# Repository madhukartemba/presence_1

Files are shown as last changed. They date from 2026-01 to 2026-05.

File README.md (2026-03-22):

# Presence 1

Presence 1 is a mmWave radar–based presence sensor featuring an ambient light sensor, NeoPixel RGB LED, and capacitive touch switch.  
It is designed for seamless integration with Home Assistant.

Build commands:
Python version 3.12
Esphome version 2026.1.2
Example: esphome -s device_id 3 run prd/presence_1_basic/presence_1_basic.yaml

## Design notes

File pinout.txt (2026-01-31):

| Device | Signal | GPIO |
| --- | --- | --- |
| LD2420 | TX → ESP | GPIO5 |
| LD2420 | RX ← ESP | GPIO4 |
| LD2420 | D-OUT | GPIO7 |
| VEML7700 | SDA | GPIO8 |
| VEML7700 | SCL | GPIO9 |
| Push Button | Input | GPIO3 |
| Neopixel | Data | GPIO6 |
| Buzzer | PWM | GPIO21 |

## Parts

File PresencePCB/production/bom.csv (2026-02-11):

Designator | Footprint | Quantity | Value | LCSC Part #
D1, D2, D3, D4, D5 | LED_WS2812B-2020_PLCC4_2.0x2.0mm | 5 | WS2812B-2020
ESP32C3 | MODULE_ESP32-C3_SUPERMINI_TH | 1 | ESP32-C3_SUPERMINI_TH
LD2420 | LD2420_Module | 1 | LD2420_Module
R_OUT1 | 0805 | 1 | 0R
TP223B1 | TP223B_Module | 1 | TP223B
VEML7700 | VEML7700_Module | 1 | VEML7700

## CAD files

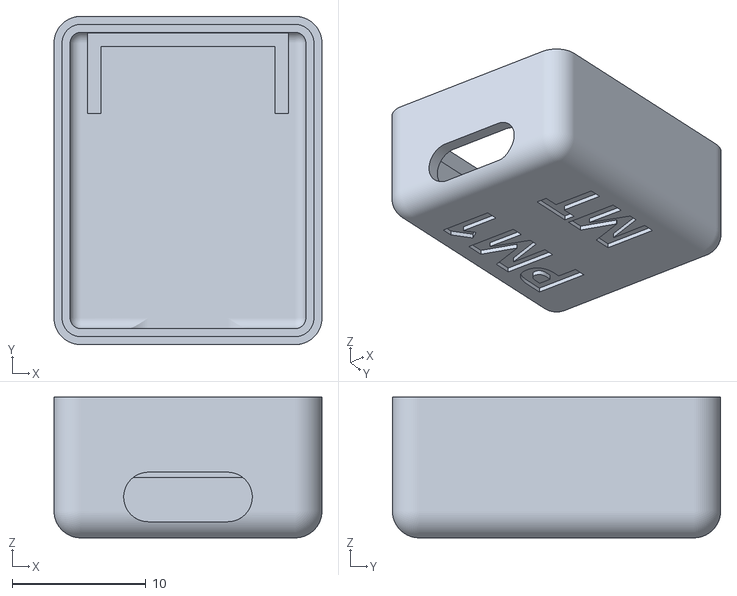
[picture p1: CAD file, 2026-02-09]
3D_print/BLE_Radar/BLE_Bottom.stl
20.0 x 24.5 x 10.5

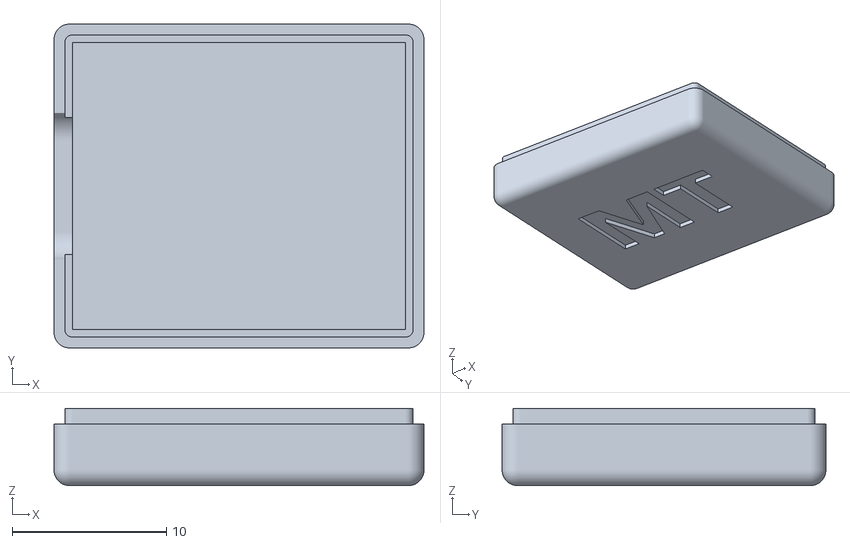
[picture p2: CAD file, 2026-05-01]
3D_print/ESP_Click_Receiver/Base.stl
24.0 x 21.0 x 5.00

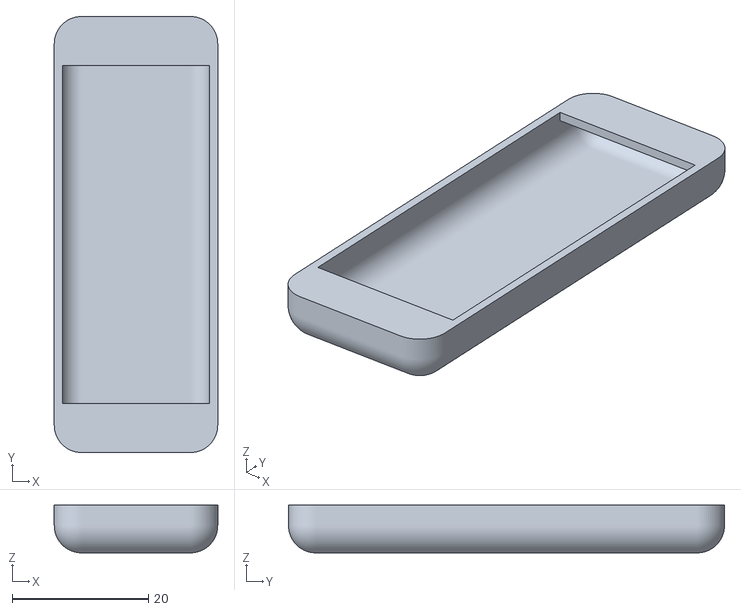
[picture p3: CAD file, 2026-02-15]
3D_print/Presence1Final/SwitchCover.stl
24.0 x 64.0 x 7.00

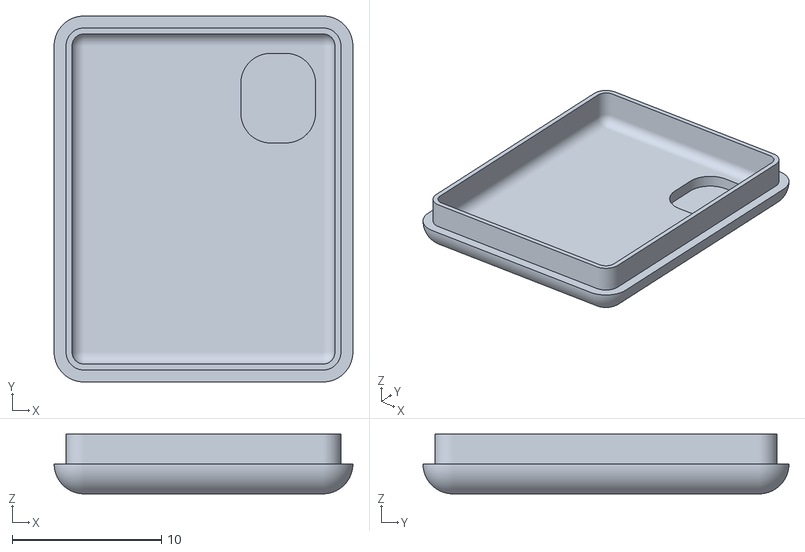
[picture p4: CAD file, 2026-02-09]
3D_print/BLE_Radar/BLE_Top.stl
20.0 x 24.5 x 4.00

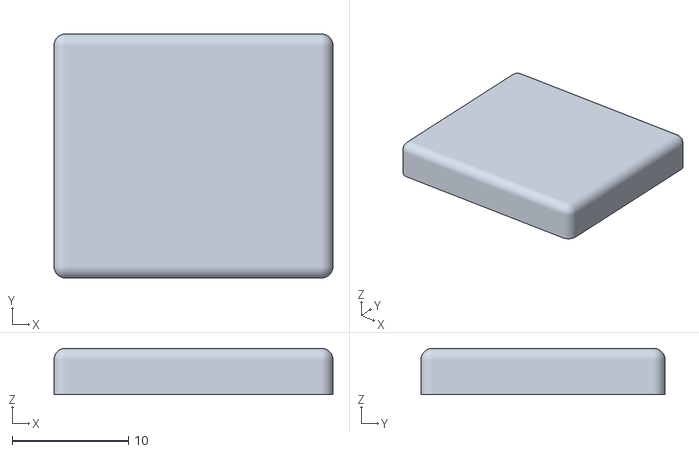
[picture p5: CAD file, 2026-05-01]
3D_print/ESP_Click_Receiver/Top.stl
24.0 x 21.0 x 4.00

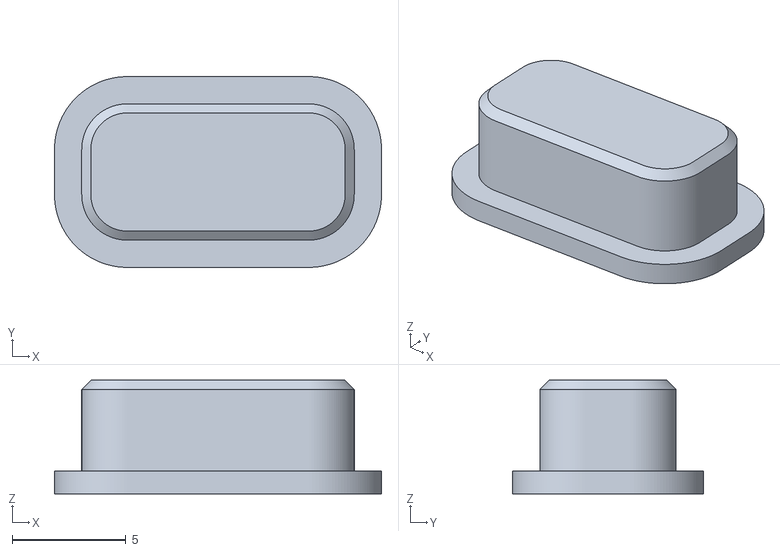
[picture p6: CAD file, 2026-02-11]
3D_print/Presence1Final/Button.stl
14.4 x 8.40 x 5.00

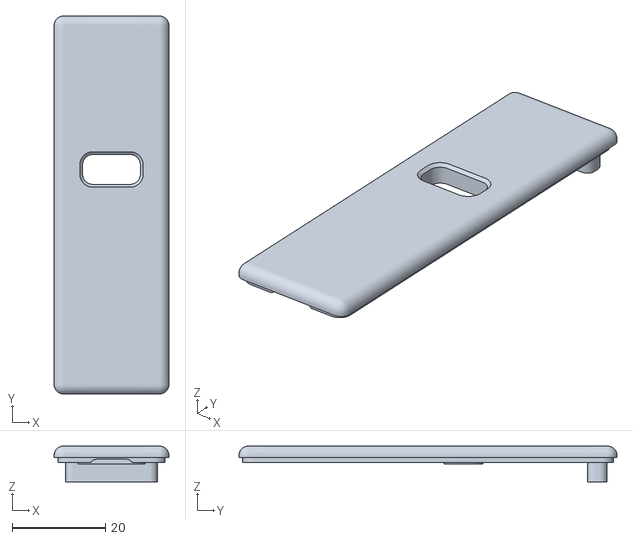
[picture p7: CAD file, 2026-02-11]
3D_print/Presence1Final/Top.stl
24.6 x 81.2 x 7.70

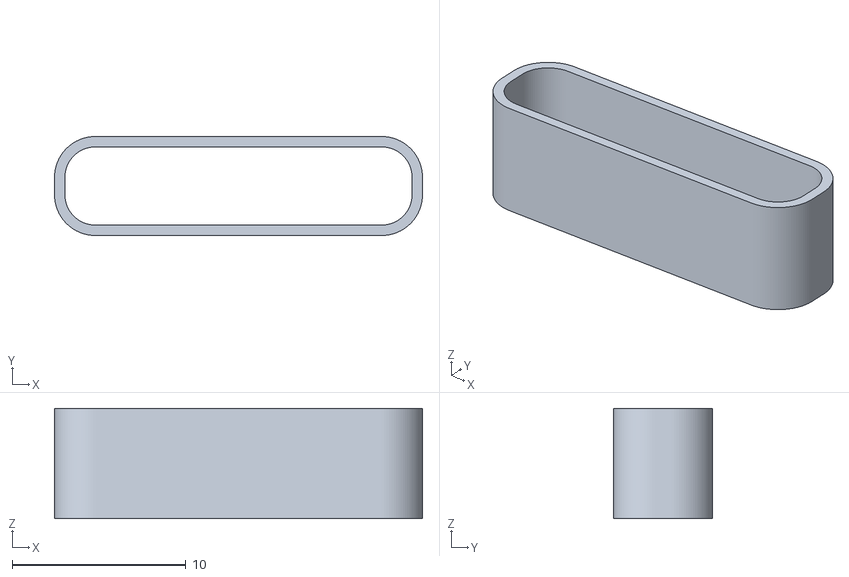
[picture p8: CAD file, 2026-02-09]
3D_print/Presence1Final/NeoCover.stl
21.2 x 5.70 x 6.35

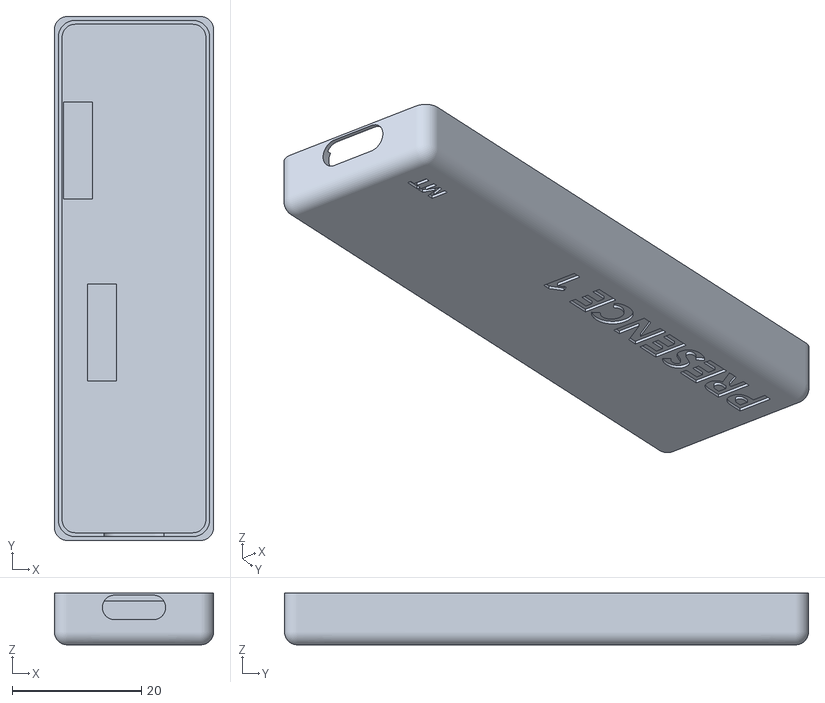
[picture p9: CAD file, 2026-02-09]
3D_print/Presence1Final/Bottom.stl
24.6 x 81.2 x 8.00

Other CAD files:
3D_print/Presence1Final/Presence 1.f3d

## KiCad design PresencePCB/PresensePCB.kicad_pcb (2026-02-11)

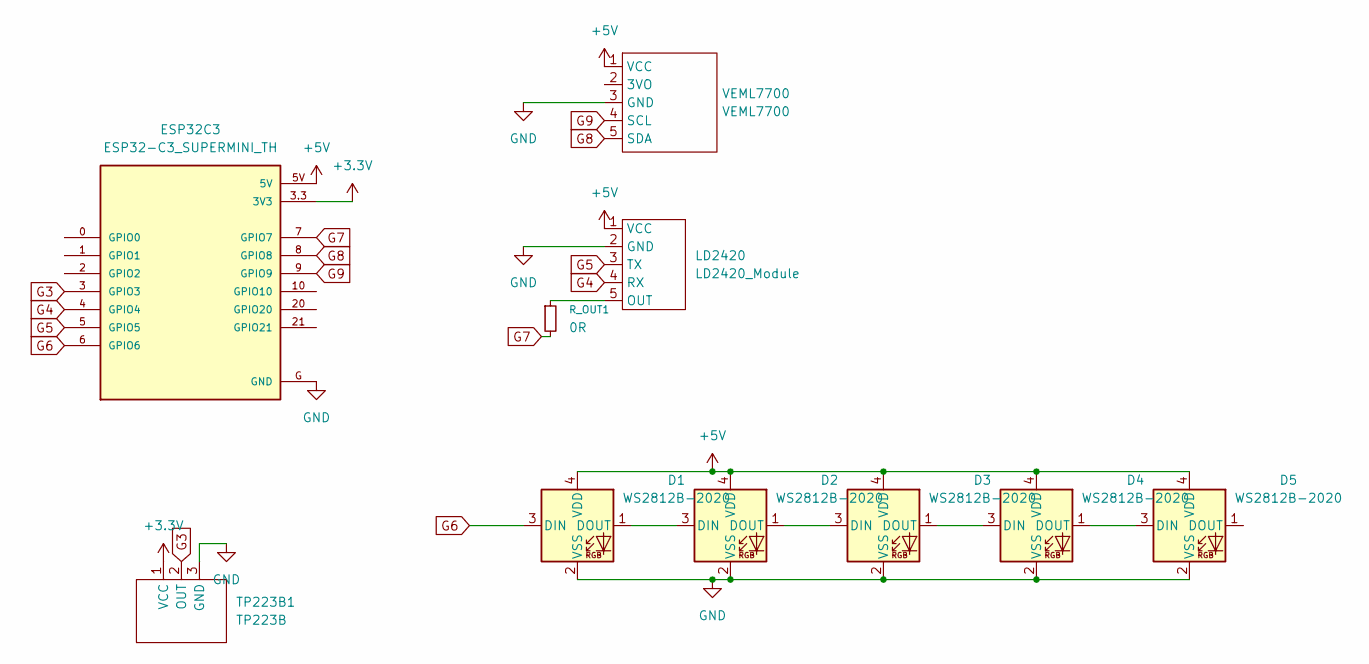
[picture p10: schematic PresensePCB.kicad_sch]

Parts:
D1, D2, D3, D4, D5: WS2812B-2020; LED_WS2812B-2020_PLCC4_2.0x2.0mm
ESP32C3: ESP32-C3_SUPERMINI_TH; MODULE_ESP32-C3_SUPERMINI_TH
LD2420: LD2420_Module
R_OUT1: 0R; R_0805_2012Metric_Pad1.20x1.40mm_HandSolder
TP223B1: TP223B; TP223B_Module
VEML7700: VEML7700; VEML7700_Module

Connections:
+3.3V: ESP32C3.3.3 (3V3), TP223B1.1 (VCC)
+5V: D1.4 (VDD), D2.4 (VDD), D3.4 (VDD), D4.4 (VDD), D5.4 (VDD), ESP32C3.5V, LD2420.1 (VCC), VEML7700.1 (VCC)
G3: ESP32C3.3 (GPIO3), TP223B1.2 (OUT)
G4: ESP32C3.4 (GPIO4), LD2420.4 (RX)
G5: ESP32C3.5 (GPIO5), LD2420.3 (TX)
G6: D1.3 (DIN), ESP32C3.6 (GPIO6)
G7: ESP32C3.7 (GPIO7), R_OUT1.2
G8: ESP32C3.8 (GPIO8), VEML7700.5 (SDA)
G9: ESP32C3.9 (GPIO9), VEML7700.4 (SCL)
GND: D1.2 (VSS), D2.2 (VSS), D3.2 (VSS), D4.2 (VSS), D5.2 (VSS), ESP32C3.G (GND), LD2420.2 (GND), TP223B1.3 (GND), VEML7700.3 (GND)
unnamed: D1.1 (DOUT), D2.3 (DIN)
unnamed: D2.1 (DOUT), D3.3 (DIN)
unnamed: D3.1 (DOUT), D4.3 (DIN)
unnamed: D4.1 (DOUT), D5.3 (DIN)
unnamed: LD2420.5 (OUT), R_OUT1.1

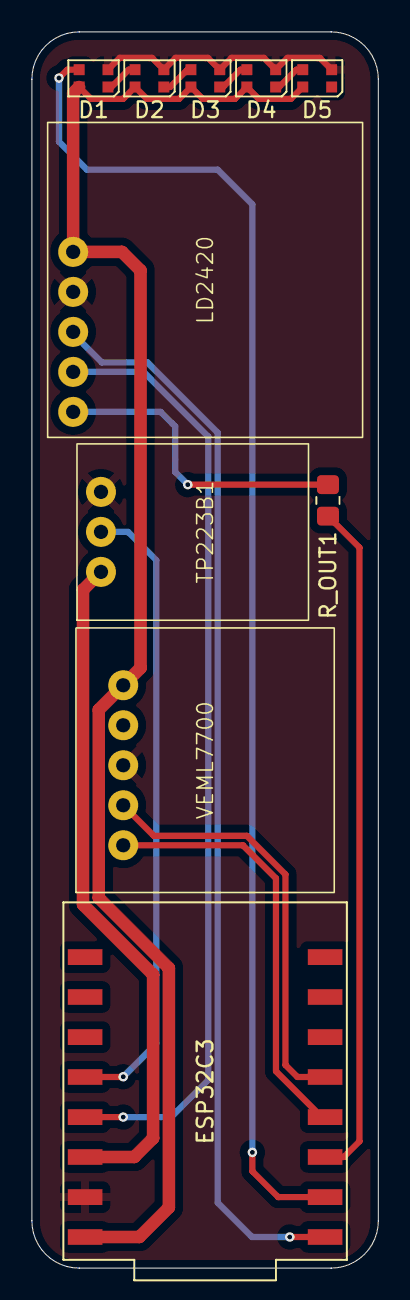
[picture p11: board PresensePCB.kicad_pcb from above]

Board: 2 copper layers, 22.0 x 78.5 mm, 10 parts (0 on the bottom side), 15 nets.

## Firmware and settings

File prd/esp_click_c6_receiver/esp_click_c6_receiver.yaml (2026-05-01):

# Minimal ESP32-C6 bridge using modular `EspClickBridge` (no LED strip).
# Copy this folder beside `esp_click_bridge/` as in this repo, or adjust `includes` paths.
substitutions:
  device_id: 0

esphome:
  name: esp-click-c6-receiver-${device_id}
  friendly_name: ESP Click C6 Receiver ${device_id}
  includes:
    - ../esp_click_bridge/esp_click_bridge.h
    - esp_now_connector.h
  platformio_options:
    lib_deps:
      - bblanchon/ArduinoJson@6.21.3
  on_boot:
    - priority: 600
      then:
        - script.execute: play_boot

esp32:
  board: esp32-c6-devkitc-1
  variant: esp32c6
  framework:
    type: esp-idf
    sdkconfig_options:
      # Work around ESP-IDF mbedTLS GCM alt-linking mismatch on C6 builds.
      # Using software AES restores standard mbedtls_gcm_* symbols.
      CONFIG_MBEDTLS_HARDWARE_AES: "n"

logger:
  level: DEBUG

api:

ota:
  - platform: esphome

wifi:
  ssid: !secret wifi_ssid
  password: !secret wifi_password
  power_save_mode: none
  on_connect:
    then:
      - script.stop: play_wifi_connecting
      - script.execute: play_wifi_connected
  on_disconnect:
    then:
      - script.execute: play_wifi_connecting

mqtt:
  broker: homeassistant.local
  username: !secret mqtt_username
  password: !secret mqtt_password
  discovery: false
  on_connect:
    - lambda: |-
        mqtt_ensure_device_sync_subscription();

espnow:
  auto_add_peer: true
  on_broadcast:
    then:
      - lambda: |-
          handle_espnow_packet(info.src_addr, data, size);
  on_receive:
    then:
      - lambda: |-
          handle_espnow_packet(info.src_addr, data, size);

# ====================
# STATUS LED (single WS2812 NeoPixel on GPIO18) — internal-only
# ====================
light:
  - platform: esp32_rmt_led_strip
    name: "Status LED"
    id: status_led
    pin: GPIO18
    num_leds: 1
    rgb_order: GRB
    chipset: WS2812
    internal: true
    default_transition_length: 0s
    # Linear gamma to avoid quantization stutter at the tail of fade-outs:
    # with gamma 2.8, ~30% of the brightness slider maps to physical 0 or 1
    # on an 8-bit WS2812, which makes the LED dwell at "1/255" before snapping
    # off. Linear keeps the steps even.
    gamma_correct: 1.0
    restore_mode: ALWAYS_OFF
    effects:
      # Slow breathing reused for pairing mode (magenta) and wifi-connecting (blue).
      # Color is captured on effect start; this effect drives brightness only.
      # Brightness range: (max_slider * 0.20) → max_slider, smoothstepped over a
      # 3 s period. Built-in `pulse` effect doesn't accept a dynamic max, so we
      # roll our own lambda effect that reads the user's max-brightness slider.
      - lambda:
          name: "Status Pulse"
          update_interval: 30ms
          lambda: |-
            static uint32_t cycle_start_ms = 0;
            if (initial_run) {
              cycle_start_ms = millis();
            }
            const uint32_t period_ms = 3000;
            const float t = (float)((millis() - cycle_start_ms) % period_ms) /
                            (float)period_ms;
            const float w = (t < 0.5f) ? (t * 2.0f) : (2.0f * (1.0f - t));
            const float s = w * w * (3.0f - 2.0f * w);
            const float max_b = id(led_max_brightness_pct).state / 100.0f;
            const float min_b = 0.20f * max_b;
            const float br = min_b + (max_b - min_b) * s;
            auto call = id(status_led).turn_on();
            call.set_transition_length(0);
            call.set_brightness(br);
            call.set_publish(false);
            call.set_save(false);
            call.perform();

interval:
  - interval: 50ms
    then:
      # Auto-close pairing mode once a device finishes pairing.
      - if:
          condition:
            lambda: return g_request_close_pairing_mode && pairing_mode_active;
          then:
            - lambda: |-
                g_request_close_pairing_mode = false;
            - switch.turn_off: pairing_mode_switch
      # Dispatch LED feedback requests latched from the EspClickBridge callback
      # (e.g. green on successful pairing, red on unpair, white/yellow/blue on
      # remote button press). See esp_now_connector.h.
      - if:
          condition:
            lambda: 'return esp_click_led_request().pending;'
          then:
            - lambda: 'esp_click_led_request().pending = false;'
            - script.execute:
                id: flash_color
                r: !lambda 'return esp_click_led_request().r / 255.0f;'
                g: !lambda 'return esp_click_led_request().g / 255.0f;'
                b: !lambda 'return esp_click_led_request().b / 255.0f;'
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

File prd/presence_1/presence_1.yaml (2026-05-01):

esphome:
  name: presence_node_${device_id}
  friendly_name: PresenceNode_${device_id}
  includes:
    - ../esp_click_bridge/esp_click_bridge.h
    - espnow_handler.h
    - led_engine.h
  platformio_options:
    lib_deps:
      - Xylopyrographer/LiteLED@3.0.1
      - bblanchon/ArduinoJson@6.21.3 # Required to parse the MAC array
  on_boot:
    - priority: 550
      then:
        - lambda: |-
            led_set_bright_lux_threshold(id(led_bright_lux_max));
    - priority: 600
      then:
        - globals.set: { id: motion_enabled, value: 'true' }
        - lambda: |-
            led_init();
            led_play_boot();

esp32:
  board: esp32-c3-devkitm-1
  framework:
    type: arduino

logger:
  baud_rate: 115200

api:

ota:
  - platform: esphome

wifi:
  ssid: !secret wifi_ssid
  password: !secret wifi_password
  power_save_mode: none
  ap:
    ssid: "PresenceNode_${device_id}_Setup"
    password: ""

captive_portal:


mqtt:
  broker: homeassistant.local
  username: !secret mqtt_username
  password: !secret mqtt_password
  discovery: false # Disable HA discovery
  # Device list: esp_click/device/<mac> handled in espnow_handler.h (needs topic + payload).
  on_connect:
    - mqtt.publish:
        topic: "esp_click/request_macs"
        payload: "fetch"
    - lambda: |-
        mqtt_ensure_device_sync_subscription();

espnow:
  auto_add_peer: true
  
  on_broadcast:
    then:
      - lambda: |-
          handle_espnow_packet(info.src_addr, data, size);

  on_receive:
    then:
      - lambda: |-
          handle_espnow_packet(info.src_addr, data, size);
          

globals:
  - id: motion_enabled
    type: bool
    restore_value: no
    initial_value: 'true'
  - id: led_bright_lux_max
    type: float
    restore_value: true
    initial_value: "10.0"

interval:
  - interval: 12ms
    then:
      - lambda: |-
          led_tick();

  - interval: 50ms
    then:
      - if:
          condition:
            lambda: return g_request_close_pairing_mode && pairing_mode_active;
          then:
            - lambda: |-
                g_request_close_pairing_mode = false;
            - switch.turn_off: pairing_mode_switch

# --------------------
# I2C
# --------------------
i2c:
  sda: GPIO8
  scl: GPIO9
  scan: true
  frequency: 100kHz

# --------------------
# UART for LD2420
# --------------------
uart:
  id: uart_mmwave
  tx_pin: GPIO4
  rx_pin: GPIO5
  baud_rate: 115200
  parity: NONE
  stop_bits: 1


ld2420:

text_sensor:
  - platform: ld2420
    fw_version:
      name: "LD2420 Firmware Version"

# ====================
# EVENT ENTITY
# ====================
event:
  - platform: template
    name: "Button"
    id: button_event
    device_class: button
    event_types:
      - single_press
      - double_press
      - long_press

# ====================
# LIGHT SENSOR
# ====================
sensor:
  - platform: ld2420
    moving_distance:
      name : Moving Distance
  - platform: veml7700
    address: 0x10
    update_interval: 1s
    ambient_light:
      name: "Ambient Light (internal)"
      id: ambient_light_lux_internal
      internal: true
      on_value:
        - lambda: |-
            led_set_ambient_lux(x);
    full_spectrum:
      name: "Full Spectrum Light (internal)"
      id: full_spectrum_lux_internal
      internal: true
    infrared:
      name: "Infrared Light (internal)"
      id: infrared_lux_internal
      internal: true
    actual_gain:
      name: "VEML7700 Gain"
    actual_integration_time:
      name: "VEML7700 Integration Time"
  - platform: template
    name: "Ambient Light"
    id: ambient_light_lux
    icon: mdi:brightness-6
    unit_of_measurement: lx
    device_class: illuminance
    state_class: measurement
    accuracy_decimals: 1
    update_interval: 30s
    lambda: |-
      return id(ambient_light_lux_internal).state;
  - platform: template
    name: "Full Spectrum Light"
    id: full_spectrum_lux
    icon: mdi:brightness-7
    unit_of_measurement: lx
    device_class: illuminance
    state_class: measurement
    accuracy_decimals: 1
    update_interval: 30s
    lambda: |-
      return id(full_spectrum_lux_internal).state;
  - platform: template
    name: "Infrared Light"
    id: infrared_lux
    icon: mdi:brightness-5
    unit_of_measurement: lx
    device_class: illuminance
    state_class: measurement
    accuracy_decimals: 1
    update_interval: 30s
    lambda: |-
      return id(infrared_lux_internal).state;
  - platform: wifi_signal
    name: "Wi-Fi Signal"
    id: wifi_signal_dbm
    update_interval: 60s
    entity_category: diagnostic
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

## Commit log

2026-02-02 pcb design complete
    [PresensePCB.kicad_pcb, PresensePCB.kicad_sch]
2026-02-02 generate pcb
    [PresensePCB.kicad_pcb, bom.csv, designators.csv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]
2026-02-09 add 3d print files
    [BLE_Bottom.stl, BLE_Top.stl, Bottom.stl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]
2026-02-09 add final 3d print
    [Button.stl, Top.stl]
2026-02-09 3d print tweaks
    [Bottom.stl, Button.stl, NeoCover.stl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]
2026-02-11 split leds
    [Presence 1.f3d, Top.stl]
2026-02-11 add chamfer
    [Button.stl, Presence 1.f3d, Top.stl]
2026-02-11 rename folders
    [BLE_Bottom.stl, BLE_Top.stl, Bottom.stl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]
2026-02-11 rename folder
    [PresensePCB.kicad_pcb, PresensePCB.kicad_sch, bom.csv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]
2026-02-13 working button events
2026-02-14 add setup portal on wifi connection failure
    [presence_1.yaml]
2026-02-14 led on ha enable
2026-02-15 add switch cover stl
    [SwitchCover.stl]
2026-02-16 increase led refresh rate
2026-02-16 Revert "increase led refresh rate"
    This reverts commit 22c12f04c50812f645e3745b02d77f6bf5996c59.
    [presence_1.yaml]
2026-02-16 Revert "integrate ld2420"
    This reverts commit 910c0aaadf66f9f79a3d8d68864568a754d1c0cf.
    [presence_1.yaml]
2026-03-23 working button
2026-03-26 working led anim
2026-04-18 fix clear devices button
    [presence_1_basic.yaml]
2026-04-19 stop pairing after one device
2026-04-19 add per device mqtt
2026-04-23 add battery status
2026-04-28 add multi device blueprint
2026-05-01 update 3d print
    [Base.stl, Top.stl]
2026-05-12 add 3d print file
2026-11-03 Receive eternal_nrf BTHome advertisements on the presence nodes.
    Home Assistant's BTHome devices stay unavailable unless a node scans and proxies those bursts.
